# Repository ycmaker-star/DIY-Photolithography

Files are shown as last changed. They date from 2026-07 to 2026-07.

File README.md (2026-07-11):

DIY-Photolithography #HACKCLUB #RaspberryPi
Attempting to create a maskless, programmable photolithography machine and safe chemical process under 200$ USD capable of sub-10 micrometer resolution in my bedroom.

The Body of Materials is in the attached excel file, many of the materials I already had, so they didn't go into the budget, furthurmore a lot of materials were stripped from used projectors (DMD, Collimating lens, fans, heatsink). Also the project was made during my time in Taiwan, so prices are in NTD and may not account for inflation (high costs in the US). 

Building Journey:

Days 1-5:
Like every good successful projects, research must be done before touching ANYTHING. Specifically, researching the internal design of projectors and how they work; Optics of photolithograhpy (especially at the micrometer resolution); chemical properties and compositions of photoresist, etchant, developer, and photoresist stripper, and finding safer/accesible alternatives; researching material wattages, power, heat production, heat dissipation. Record everything in the Engineering Notebook.

Days 6-9:
I brainstormed and sketched the architecture/design of the photolithography machine in my engineering notebook. I drew 4 different possible variations of the design and weighed the pros and cons. I've come to learn that having multiple design iterations are completely normal, and finally ended up on this one 

Day 10:
The chemicals arrived. A 1-3% (by weight) aqueous Sodium Carbonate (Na2CO3) solution acts as the developer for photoresist. A 2-5% (by weight) aquueous Sodium Hydroxide (NaOH) solution acts as the final photoresist stripper. Extra pure IPA is the original substrate cleaner. These chemicals, although not as dangerous as the ones typically used by industries, are still strong irritants and should be stored in dark, cool, low moisture enviornemnts. For me, I stored them in airtight glass jars (Never use metal containers) and put a Silica Moisture remover packet in each one. 

Day 11-14:
Now for the fun part, CADing the design and prepping for 3D printing. Personally, I like using onshape due to my familiarity with VEX robotics. This part isn't very arduous as only a small portion of the machine is 3D printed (the adapter). The main purpose of the Adapter is to house the 50-50 beam splitter and direct the UV light from DMD down to the 10x lens and hence substrate, but also letting the camera aim down. It also serves as UV light dissipater. The STL file will be attached.

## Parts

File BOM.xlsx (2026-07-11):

CHEMICALS Materials | Specs | Cost (NTD), N/A=owned
Photoresist | negative 405nm cureable | 1250
Isopropyl Alchol | Clean substrate 99% IPA | 136
Developer | 4% Sodium Carbonate (aq) | 26
Etchant | Diluted warm hcl | ~200
Photoresist stripper | NaOH 2-5% (aq), naoh pellets | 25
Wafer
ITO glass for now | 50x50mm 25pcs | 980
EXPOSURE
UV LED | 405nm Chip on board | 395
DMD | 5.5-6.5" & 4k-8k res | 700
Collimating lens | Aspheric glass | N/A
Magnification | 10x microscope lens | 414
Beam splitter for view | 50-50 split for uv & allign | 400
Camera | Connect RPI to view | N/A
Relay Board | allows rpi to ctrl uv w/o fry | 28
COOLING
Heat dissapation tape | Connect to heatsink (3cm) | 210
Heat sink | Stick to back of DMD & UV | N/A
Cpu FAN | ~2000+ rpm | N/A
Z STAGE
Z axis | mechanical knob lift | 370
XY STAGE
Rail+motors | Leadscrew, stepper motor, 3.125mm | 578
step motor driver | TMC 2209 x2 + 1 xtra | 270
CNC shield v3 | put on arduino | 50
Arduino Uno | Control stepper motor via rpi | N/A
MISC
Spin Coater | PC fan ~2k+ rpm & Plastic | N/A
Hot plate | Bake photoresist Up to 120C | 550
3D printer + filament | Using my friend's | N/A
Containers/beakers | Not METAL! | N/A
Saftey | Goggles, gloves, sleeves | ~500
Multimeter | for testing/saftey/probe | 199
 | Total (NTD): | 6581

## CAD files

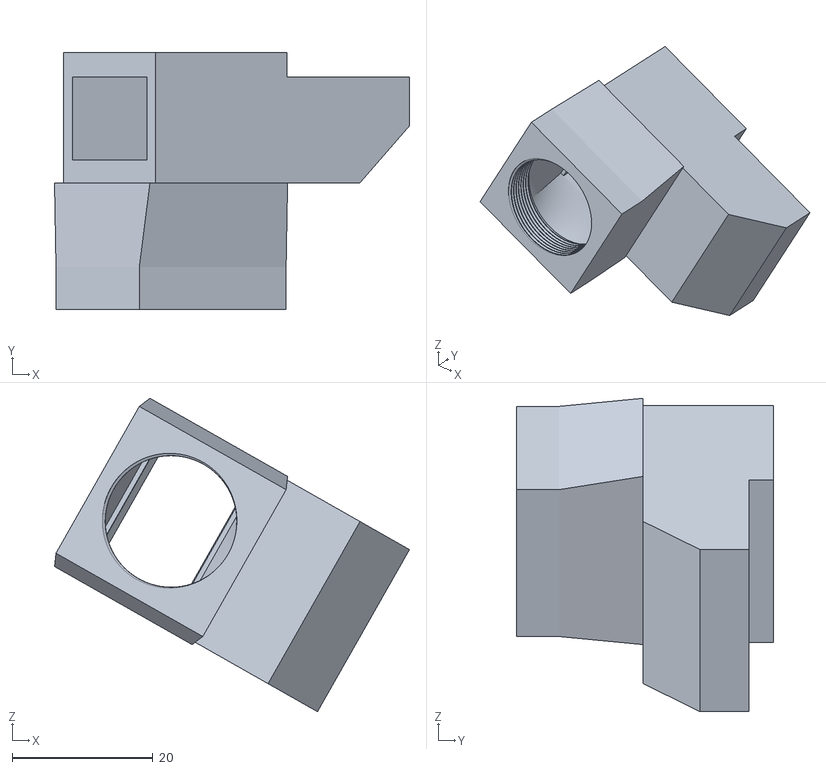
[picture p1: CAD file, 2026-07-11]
Adapter.stl
50.5 x 36.5 x 44.6
